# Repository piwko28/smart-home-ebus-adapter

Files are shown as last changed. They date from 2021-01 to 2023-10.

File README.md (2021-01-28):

# eBUS Adapter for ESP8622

eBUS adapter PCB for use with [ebusd-esp](https://github.com/john30/ebusd-esp) firmware as well as with other UART devices.

Schematic inspired by [ebus adapter 2](https://github.com/eBUS/adapter), so it inherits GPL license.

## Schematic

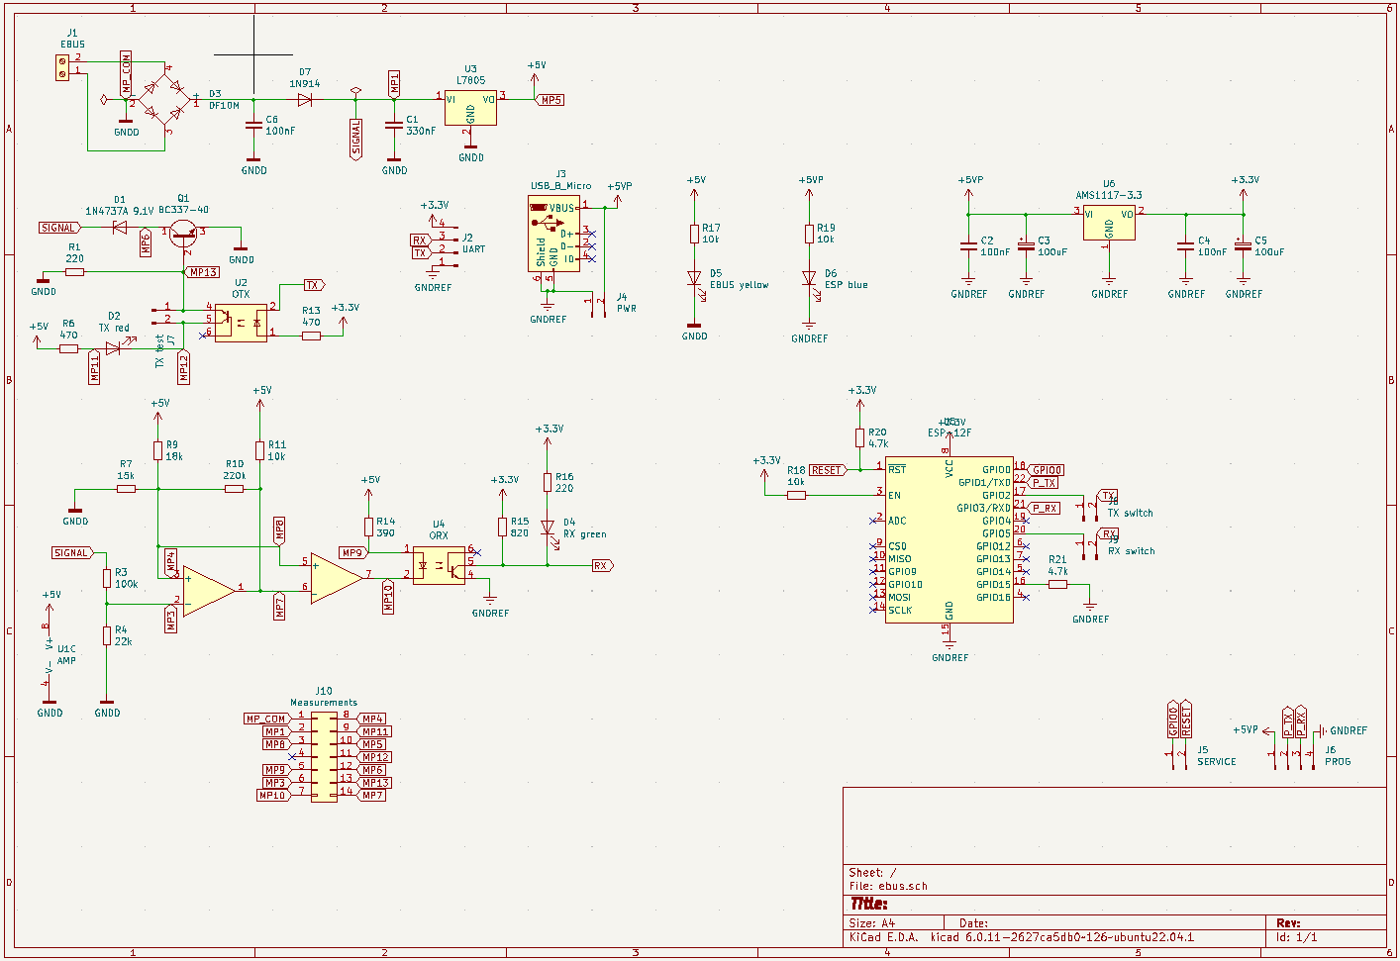
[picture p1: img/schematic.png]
Schematic


## PCB design

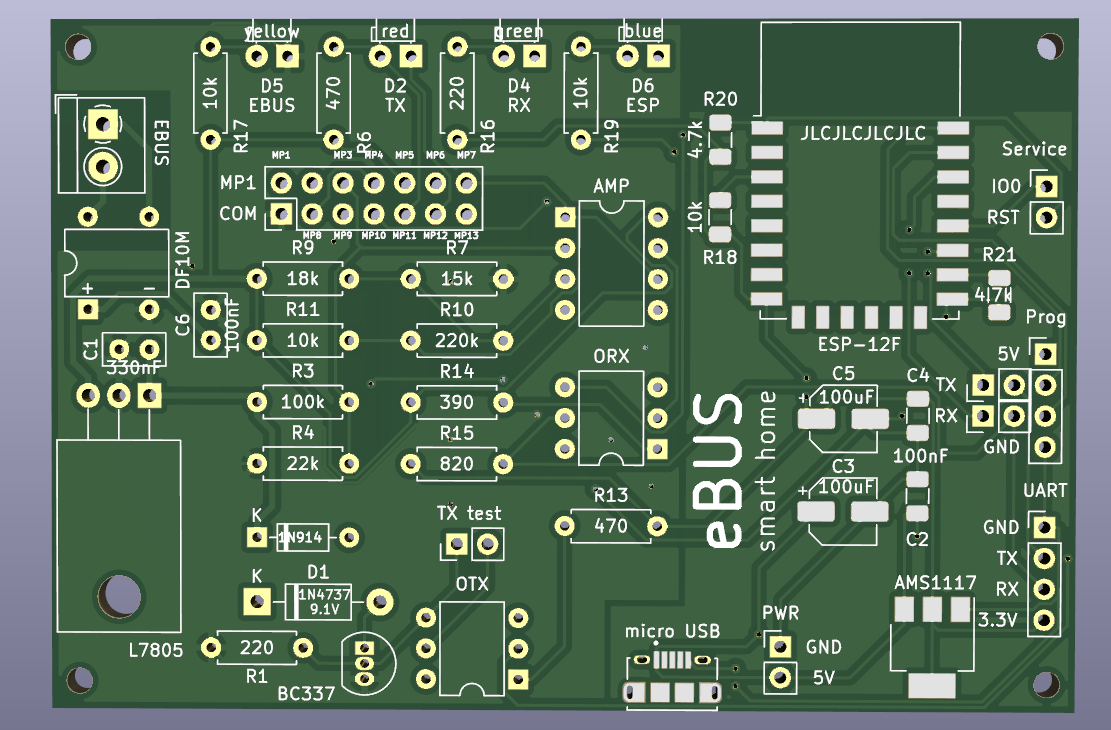
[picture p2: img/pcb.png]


## Box design

The box design is for 3d printing.

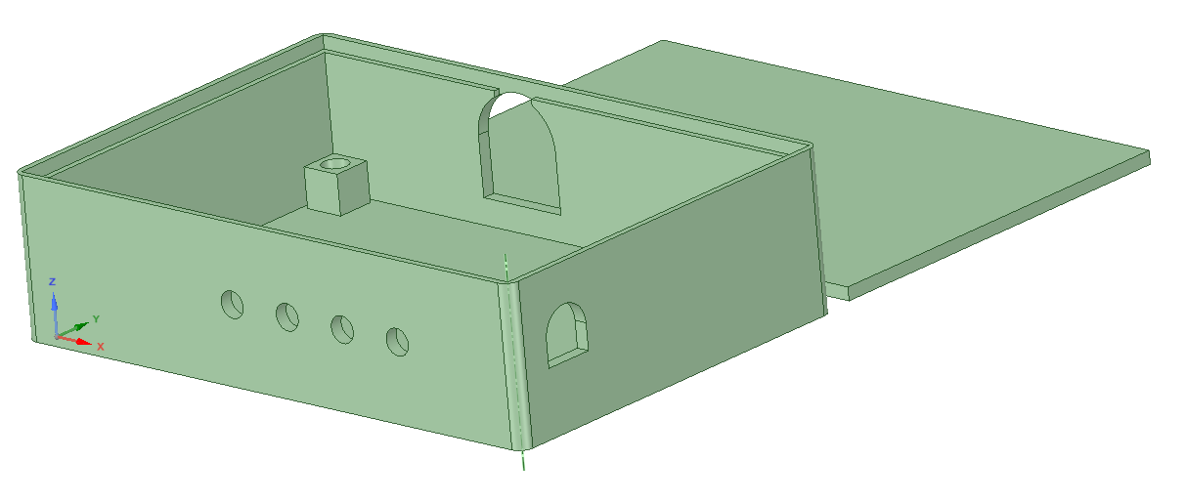
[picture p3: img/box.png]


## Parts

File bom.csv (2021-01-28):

Label | Quantity | Part name | Package
4N25 | 2 | 4N25 | DIP-6_W7.62mm
C4,C2 | 2 | 100nF | C_1206_3216Metric
R21,R20 | 2 | 4.7k | R_1206_3216Metric
R18 | 1 | 10k | R_1206_3216Metric
AMS1117 | 1 | AMS1117-3.3 | SOT-223-3_TabPin2
ESP-12F | 1 | ESP-12F | ESP-12E
L7805 | 1 | L7805 | TO-220-3_Horizontal_TabDown
LM393P | 1 | LM393 | DIP-8_W7.62mm
R14 | 1 | 2.2k | R_Axial_DIN0207_L6.3mm_D2.5mm_P7.62mm_Horizontal
R19,R17,R11,R2 | 4 | 10k | R_Axial_DIN0207_L6.3mm_D2.5mm_P7.62mm_Horizontal
R16,R1 | 2 | 220 | R_Axial_DIN0207_L6.3mm_D2.5mm_P7.62mm_Horizontal
R15 | 1 | 1k | R_Axial_DIN0207_L6.3mm_D2.5mm_P7.62mm_Horizontal
R13,R6 | 2 | 470 | R_Axial_DIN0207_L6.3mm_D2.5mm_P7.62mm_Horizontal
R12 | 1 | 4.7k | R_Axial_DIN0207_L6.3mm_D2.5mm_P7.62mm_Horizontal
R10,R9 | 2 | 220k | R_Axial_DIN0207_L6.3mm_D2.5mm_P7.62mm_Horizontal
R8,R4 | 2 | 20k | R_Axial_DIN0207_L6.3mm_D2.5mm_P7.62mm_Horizontal
R7 | 1 | 5.1k | R_Axial_DIN0207_L6.3mm_D2.5mm_P7.62mm_Horizontal
R5 | 1 | 2k | R_Axial_DIN0207_L6.3mm_D2.5mm_P7.62mm_Horizontal
R3 | 1 | 100k | R_Axial_DIN0207_L6.3mm_D2.5mm_P7.62mm_Horizontal
BC337 | 1 | BC337 | TO-92_Inline
Prog | 1 | PROG | PinHeader_1x04_P2.54mm_Vertical
Service | 1 | SERVICE | PinHeader_1x02_P2.54mm_Vertical
PWR | 1 | PWR | PinHeader_1x02_P2.54mm_Vertical
micro USB | 1 | USB_B_Micro | USB_Micro-B_Wuerth_629105150521
UART | 1 | UART | PinHeader_1x04_P2.54mm_Vertical
J1 | 1 | EBUS | TerminalBlock_4Ucon_1x02_P3.50mm_Horizontal
D7 | 1 | 1N914 | DO35
D6 | 1 | ESP blue | LED_D3.0mm_Horizontal_O1.27mm_Z2.0mm
D5 | 1 | EBUS yellow | LED_D3.0mm_Horizontal_O1.27mm_Z2.0mm
D4 | 1 | RX green | LED_D3.0mm_Horizontal_O1.27mm_Z2.0mm
DF10M | 1 | DF10M | Diode_Bridge_DIP-4_W7.62mm_P5.08mm
D2 | 1 | TX red | LED_D3.0mm_Horizontal_O1.27mm_Z2.0mm
D1 | 1 | 1N4737A 7.5V | D_DO-41_SOD81_P10.16mm_Horizontal
C5,C3 | 2 | 100uF | CP_Elec_5x5.7
C1 | 1 | 330nF | C_Disc_D5.0mm_W2.5mm_P2.50mm
C6 | 1 | 100nF | C_Disc_D5.0mm_W2.5mm_P2.50mm

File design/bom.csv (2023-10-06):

Source: | /home/szymon/Projects/smart-home/ebus/ebus/design/ebus.sch
Date: | Wed 03 Nov 2021 11:00:56 CET
Tool: | Eeschema 5.1.5+dfsg1-2build2
Component Count: | 47
Ref | Value | Footprint | Datasheet | Manufacturer | Vendor
C1 | 330nF | Capacitor_THT:C_Disc_D5.0mm_W2.5mm_P2.50mm | ~
C2 | 100nF | Capacitor_SMD:C_1206_3216Metric | ~
C3 | 100uF | Capacitor_SMD:CP_Elec_5x5.7 | ~
C4 | 100nF | Capacitor_SMD:C_1206_3216Metric | ~
C5 | 100uF | Capacitor_SMD:CP_Elec_5x5.7 | ~
C6 | 100nF | Capacitor_THT:C_Disc_D5.0mm_W2.5mm_P2.50mm | ~
D1 | 1N4737A 9.1V | Diode_THT:D_DO-41_SOD81_P10.16mm_Horizontal | http://www.vishay.com/docs/85790/zpy3v9.pdf
D2 | TX red | LED_THT:LED_D3.0mm_Horizontal_O1.27mm_Z2.0mm | ~
D3 | DF10M | Diode_THT:Diode_Bridge_DIP-4_W7.62mm_P5.08mm | http://www.vishay.com/docs/88571/dfm.pdf
D4 | RX green | LED_THT:LED_D3.0mm_Horizontal_O1.27mm_Z2.0mm | ~
D5 | EBUS yellow | LED_THT:LED_D3.0mm_Horizontal_O1.27mm_Z2.0mm | ~
D6 | ESP blue | LED_THT:LED_D3.0mm_Horizontal_O1.27mm_Z2.0mm | ~
D7 | 1N914 | Diode_THT:D_DO-35_SOD27_P7.62mm_Horizontal | http://www.vishay.com/docs/85622/1n914.pdf
J1 | EBUS | TerminalBlock_4Ucon:TerminalBlock_4Ucon_1x02_P3.50mm_Horizontal | ~
J2 | UART | Connector_PinHeader_2.54mm:PinHeader_1x04_P2.54mm_Vertical | ~
J3 | USB_B_Micro | Connector_USB:USB_Micro-B_Wuerth_629105150521 | ~
J4 | PWR | Connector_PinHeader_2.54mm:PinHeader_1x02_P2.54mm_Vertical | ~
J5 | SERVICE | Connector_PinHeader_2.54mm:PinHeader_1x02_P2.54mm_Vertical | ~
J6 | PROG | Connector_PinHeader_2.54mm:PinHeader_1x04_P2.54mm_Vertical | ~
J7 | TX test | Connector_PinHeader_2.54mm:PinHeader_1x02_P2.54mm_Vertical | ~
J8 | TX switch | Connector_PinHeader_2.54mm:PinHeader_1x02_P2.54mm_Vertical | ~
J9 | RX switch | Connector_PinHeader_2.54mm:PinHeader_1x02_P2.54mm_Vertical | ~
J10 | Measurements | Connector_PinHeader_2.54mm:PinHeader_2x07_P2.54mm_Vertical | ~
Q1 | BC337-40 | Package_TO_SOT_THT:TO-92_Inline | https://diotec.com/tl_files/diotec/files/pdf/datasheets/bc337.pdf
R1 | 220 | Resistor_THT:R_Axial_DIN0207_L6.3mm_D2.5mm_P7.62mm_Horizontal | ~
R3 | 100k | Resistor_THT:R_Axial_DIN0207_L6.3mm_D2.5mm_P7.62mm_Horizontal | ~
R4 | 22k | Resistor_THT:R_Axial_DIN0207_L6.3mm_D2.5mm_P7.62mm_Horizontal | ~
R6 | 470 | Resistor_THT:R_Axial_DIN0207_L6.3mm_D2.5mm_P7.62mm_Horizontal | ~
R7 | 15k | Resistor_THT:R_Axial_DIN0207_L6.3mm_D2.5mm_P7.62mm_Horizontal | ~
R9 | 18k | Resistor_THT:R_Axial_DIN0207_L6.3mm_D2.5mm_P7.62mm_Horizontal | ~
R10 | 220k | Resistor_THT:R_Axial_DIN0207_L6.3mm_D2.5mm_P7.62mm_Horizontal | ~
R11 | 10k | Resistor_THT:R_Axial_DIN0207_L6.3mm_D2.5mm_P7.62mm_Horizontal | ~
R13 | 470 | Resistor_THT:R_Axial_DIN0207_L6.3mm_D2.5mm_P7.62mm_Horizontal | ~
R14 | 390 | Resistor_THT:R_Axial_DIN0207_L6.3mm_D2.5mm_P7.62mm_Horizontal | ~
R15 | 820 | Resistor_THT:R_Axial_DIN0207_L6.3mm_D2.5mm_P7.62mm_Horizontal | ~
R16 | 220 | Resistor_THT:R_Axial_DIN0207_L6.3mm_D2.5mm_P7.62mm_Horizontal | ~
R17 | 10k | Resistor_THT:R_Axial_DIN0207_L6.3mm_D2.5mm_P7.62mm_Horizontal | ~
R18 | 10k | Resistor_SMD:R_1206_3216Metric | ~
R19 | 10k | Resistor_THT:R_Axial_DIN0207_L6.3mm_D2.5mm_P7.62mm_Horizontal | ~
R20 | 4.7k | Resistor_SMD:R_1206_3216Metric | ~
R21 | 4.7k | Resistor_SMD:R_1206_3216Metric | ~
U1 | AMP | Package_DIP:DIP-8_W7.62mm | http://www.ti.com/lit/ds/symlink/lm393.pdf
U2 | OTX | Package_DIP:DIP-6_W7.62mm | http://www.ti.com/lit/ds/symlink/lm393.pdf
U3 | L7805 | Package_TO_SOT_THT:TO-220-3_Horizontal_TabDown | http://www.ti.com/lit/ds/symlink/lm393.pdf
U4 | ORX | Package_DIP:DIP-6_W7.62mm | http://www.ti.com/lit/ds/symlink/lm393.pdf
U5 | ESP-12F | RF_Module:ESP-12E | http://wiki.ai-thinker.com/_media/esp8266/esp8266_series_modules_user_manual_v1.1.pdf
U6 | AMS1117-3.3 | Package_TO_SOT_SMD:SOT-223-3_TabPin2 | http://www.advanced-monolithic.com/pdf/ds1117.pdf

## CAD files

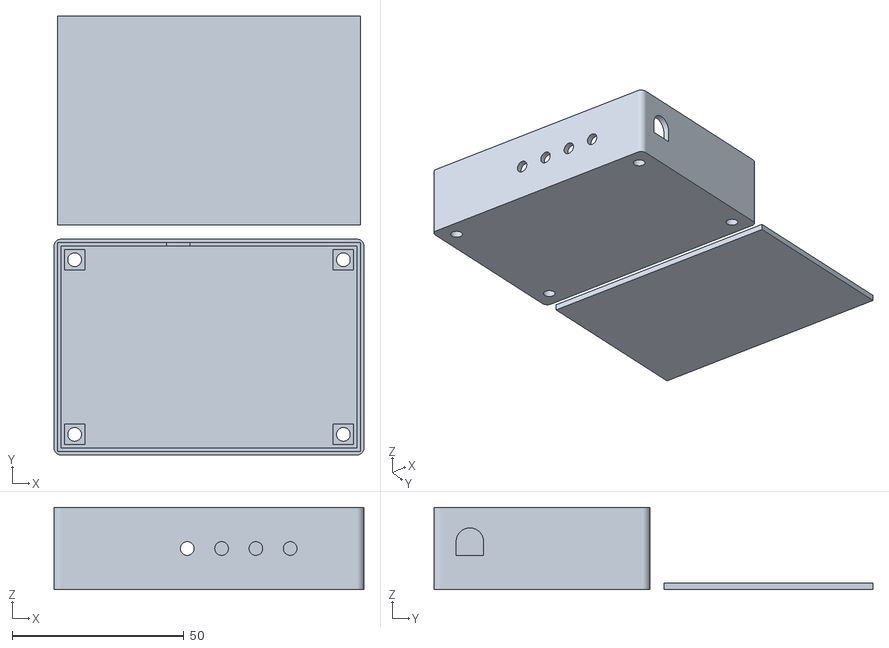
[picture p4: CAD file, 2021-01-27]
box/ebus.stl
90.3 x 127.9 x 24.0

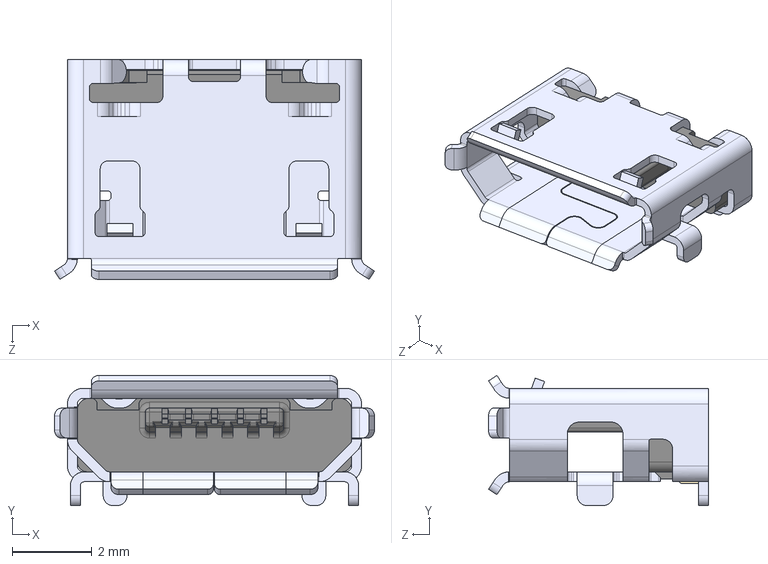
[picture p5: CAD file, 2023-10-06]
design/usb/10118194-0001LF.step
8.05 x 3.27 x 5.53 mm

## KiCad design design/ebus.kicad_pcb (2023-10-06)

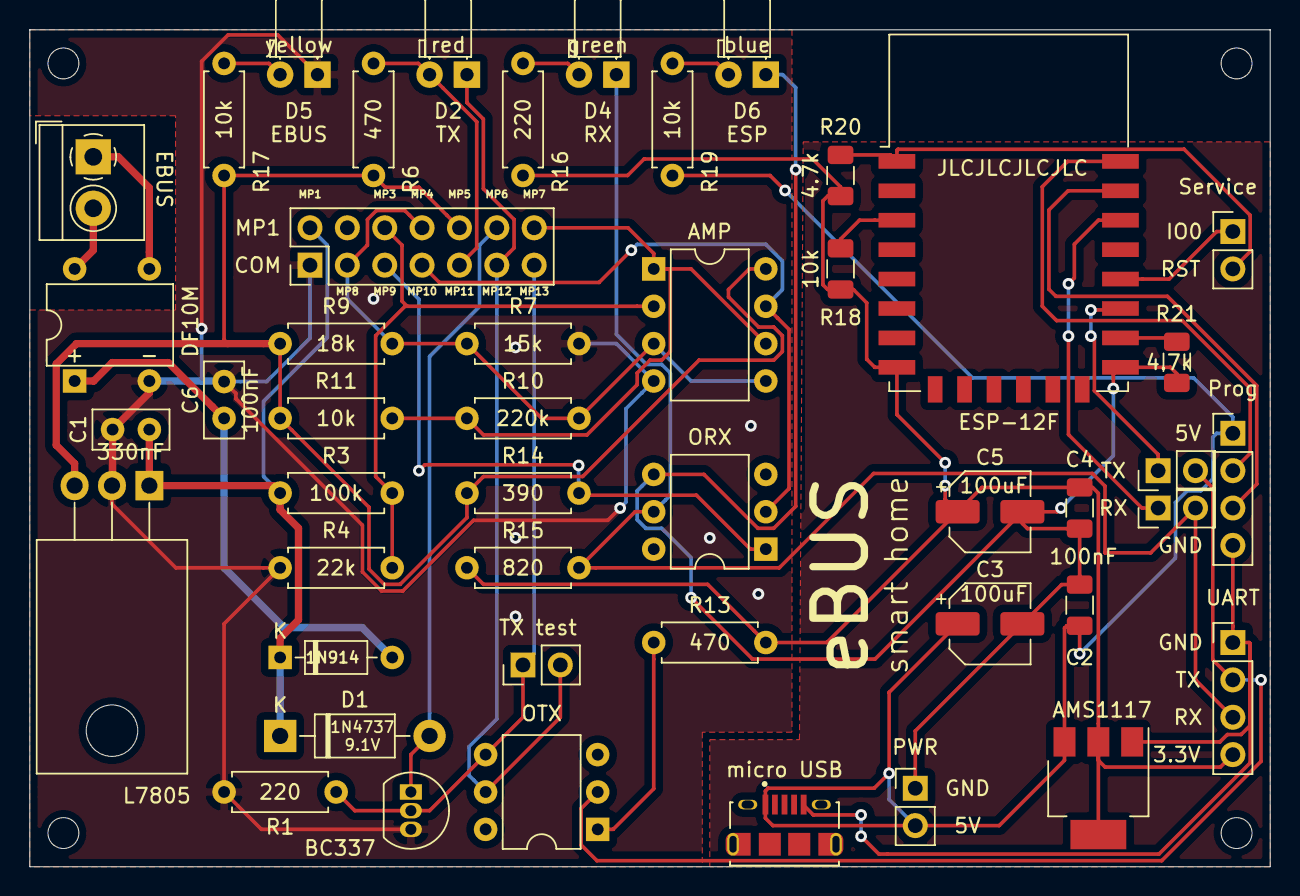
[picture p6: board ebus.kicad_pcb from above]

Board: 2 copper layers, 84.3 x 56.9 mm, 47 parts (0 on the bottom side), 32 nets.

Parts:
C1: 330nF; C_Disc_D5.0mm_W2.5mm_P2.50mm
C2, C4: 100nF; C_1206_3216Metric
C3, C5: 100uF; CP_Elec_5x5.7
C6: 100nF; C_Disc_D5.0mm_W2.5mm_P2.50mm
D1: 1N4737A 9.1V; D_DO-41_SOD81_P10.16mm_Horizontal
D2: TX red; LED_D3.0mm_Horizontal_O1.27mm_Z2.0mm
D3: DF10M; Diode_Bridge_DIP-4_W7.62mm_P5.08mm
D4: RX green; LED_D3.0mm_Horizontal_O1.27mm_Z2.0mm
D5: EBUS yellow; LED_D3.0mm_Horizontal_O1.27mm_Z2.0mm
D6: ESP blue; LED_D3.0mm_Horizontal_O1.27mm_Z2.0mm
D7: 1N914; D_DO-35_SOD27_P7.62mm_Horizontal
J1: EBUS; TerminalBlock_4Ucon_1x02_P3.50mm_Horizontal
J2: UART; PinHeader_1x04_P2.54mm_Vertical
J3: USB_B_Micro; AMPHENOL_10118194-0001LF
J4: PWR; PinHeader_1x02_P2.54mm_Vertical
J5: SERVICE; PinHeader_1x02_P2.54mm_Vertical
J6: PROG; PinHeader_1x04_P2.54mm_Vertical
J7: TX test; PinHeader_1x02_P2.54mm_Vertical
J8: TX switch; PinHeader_1x02_P2.54mm_Vertical
J9: RX switch; PinHeader_1x02_P2.54mm_Vertical
J10: Measurements; PinHeader_2x07_P2.54mm_Vertical
Q1: BC337-40; TO-92_Inline
R1, R16: 220; R_Axial_DIN0207_L6.3mm_D2.5mm_P7.62mm_Horizontal
R3: 100k; R_Axial_DIN0207_L6.3mm_D2.5mm_P7.62mm_Horizontal
R4: 22k; R_Axial_DIN0207_L6.3mm_D2.5mm_P7.62mm_Horizontal
R6, R13: 470; R_Axial_DIN0207_L6.3mm_D2.5mm_P7.62mm_Horizontal
R7: 15k; R_Axial_DIN0207_L6.3mm_D2.5mm_P7.62mm_Horizontal
R9: 18k; R_Axial_DIN0207_L6.3mm_D2.5mm_P7.62mm_Horizontal
R10: 220k; R_Axial_DIN0207_L6.3mm_D2.5mm_P7.62mm_Horizontal
R11, R17, R19: 10k; R_Axial_DIN0207_L6.3mm_D2.5mm_P7.62mm_Horizontal
R14: 390; R_Axial_DIN0207_L6.3mm_D2.5mm_P7.62mm_Horizontal
R15: 820; R_Axial_DIN0207_L6.3mm_D2.5mm_P7.62mm_Horizontal
R18: 10k; R_1206_3216Metric
R20, R21: 4.7k; R_1206_3216Metric
U1: AMP; DIP-8_W7.62mm
U2: OTX; DIP-6_W7.62mm
U3: L7805; TO-220-3_Horizontal_TabDown
U4: ORX; DIP-6_W7.62mm
U5: ESP-12F; ESP-12E
U6: AMS1117-3.3; SOT-223-3_TabPin2

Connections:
+3V3: C4.1, C5.1, J2.4, R13.1, R15.2, R16.2, R18.1, R20.2, U5.8, U6.2
+5VP: C2.1, C3.1, J3.1, J4.2, J6.1, R19.2, U6.3
GNDREF: C2.2, C3.2, C4.2, C5.2, D6.1, J2.1, J3.5, J4.1, J6.4, R21.2, U4.4, U5.15, U6.1
GPIO0: J5.1, U5.18
MP1: C1.1, D1.1, D7.1, J10.2, R3.2, U3.1
MP3: J10.6, R3.1, R4.2, U1.2
MP4: J10.3, J10.8, R7.1, R9.1, R10.2, U1.3, U1.5
MP5: J10.10, R6.2, R9.2, R11.2, R14.2, R17.2, U1.8, U3.3
MP6: D1.2, J10.12, Q1.1
MP7: J10.14, R10.1, R11.1, U1.1, U1.6
MP9: J10.5, R14.1, U4.1
MP10: J10.7, U1.7, U4.2
MP11: D2.2, J10.9, R6.1
MP12: D2.1, J7.2, J10.11, U2.5
MP13: J7.1, J10.13, Q1.2, R1.1, U2.4
MP_COM: C1.2, C6.2, D3.2, D5.1, J10.1, Q1.3, R1.2, R4.1, R7.2, U1.4, U3.2
unnamed: C6.1, D3.1, D7.2
unnamed: D3.3, J1.1
unnamed: D3.4, J1.2
unnamed: D4.2, R16.1
unnamed: D5.2, R17.1
unnamed: D6.2, R19.1
unnamed: J8.1, U5.17
unnamed: J9.1, U5.20
unnamed: R13.2, U2.1
unnamed: R18.2, U5.3
unnamed: R21.1, U5.16
P_RX: J6.3, U5.21
P_TX: J6.2, U5.22
RESET: J5.2, R20.1, U5.1
RX: D4.1, J2.3, J9.2, R15.1, U4.5
TX: J2.2, J8.2, U2.2

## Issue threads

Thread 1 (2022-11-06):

Is this schematic tested on real devices?

ashumkin, 2022-11-06:
Hello!
Have you manufactured a PCB and tested it? Does it really work? Also, the SMD version?
I'm looking for alternatives for the components used in the [original schematic ](https://adapter.ebusd.eu/v2/index.en.html) and your schematic LGTM ))

Also, what were the reasons to use parallel and sequential connections of resistors (e.g. R4+R5, R2+R7, R8+R9)?

ashumkin, 2022-11-13:
any response?

bbilas, 2023-02-19:
@ashumkin have you already verified that on your own? I also want to order the pcbs so this information would be useful.

ashumkin, 2023-02-19:
@bbilas, unfortunately, not yet. I hope to do it but with no deadline :)

piwko28, 2023-10-06:
@ashumkin I've updated the schematics, incl. smd version. It's been tested on many devices and boilers. I'll put there measuring points voltage values and updated housing soon.

Closed 2024-10-07.

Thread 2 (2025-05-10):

What components use?

matid28, 2025-05-10:
@piwko28
What electronic components did you use in place of the AMP, OTX and ORX?
Is the use for the OTX and ORX - 4N25 ok?
Can I use LM358, TLC393CP or something else for the AMP?

piwko28, 2025-05-11:
4N25 is fine, LM393 as amp.
Here is billing of materials: https://github.com/piwko28/smart-home-ebus-adapter/blob/master/bom.csv

Newer version: https://github.com/piwko28/smart-home-ebus-adapter/tree/raspberry
You can open the schematic with KiCAD.

Closed 2025-05-11.

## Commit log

2021-01-27 Ebus adapter init
    [ebus.kicad_pcb, ebus.sch]
2021-01-27 PCB redesigned and with labels
    [ebus.kicad_pcb]
2021-01-27 Gerber files
    [bom.csv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]
2021-01-27 Box design
    [ebus.stl]
2021-01-28 Mistake in R14 resistor value fix
    [bom.csv, ebus.sch]
2021-01-28 Clean up repository
    [ebus.kicad_pcb, ebus.sch]
2021-01-28 Voltage regulator changes, some graphical improvements of pcb
    [bom.csv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]
2021-10-29 PCB v1.1 - added measurements points, reduced number of resistors, changed components values
    [ebus-B_Cu.gbr, ebus-B_Mask.gbr, ebus-B_SilkS.gbr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]
2021-11-03 Change usb socket footprint
    [10118194-0001LF.step, bom.csv, ebus.kicad_pcb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]
2021-11-27 Fix missing track
    [ebus.kicad_pcb]
